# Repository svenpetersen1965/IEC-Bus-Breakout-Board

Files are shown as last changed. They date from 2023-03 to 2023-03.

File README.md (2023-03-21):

# IEC-Bus-Breakout-Board
This is a breakout board for the Commodore C64/C128/C16/VIC-20 etc. IEC-Bus. The Purpose is connecting the IEC-Bus to a µController or miniComputer, like an Arduino, a Raspberry Pi (zero, pico, Pi1-4) etc.

It provides the required interface ICs and even 5V to 3.3V level shifters, which are required for e.g. the raspberry pis.

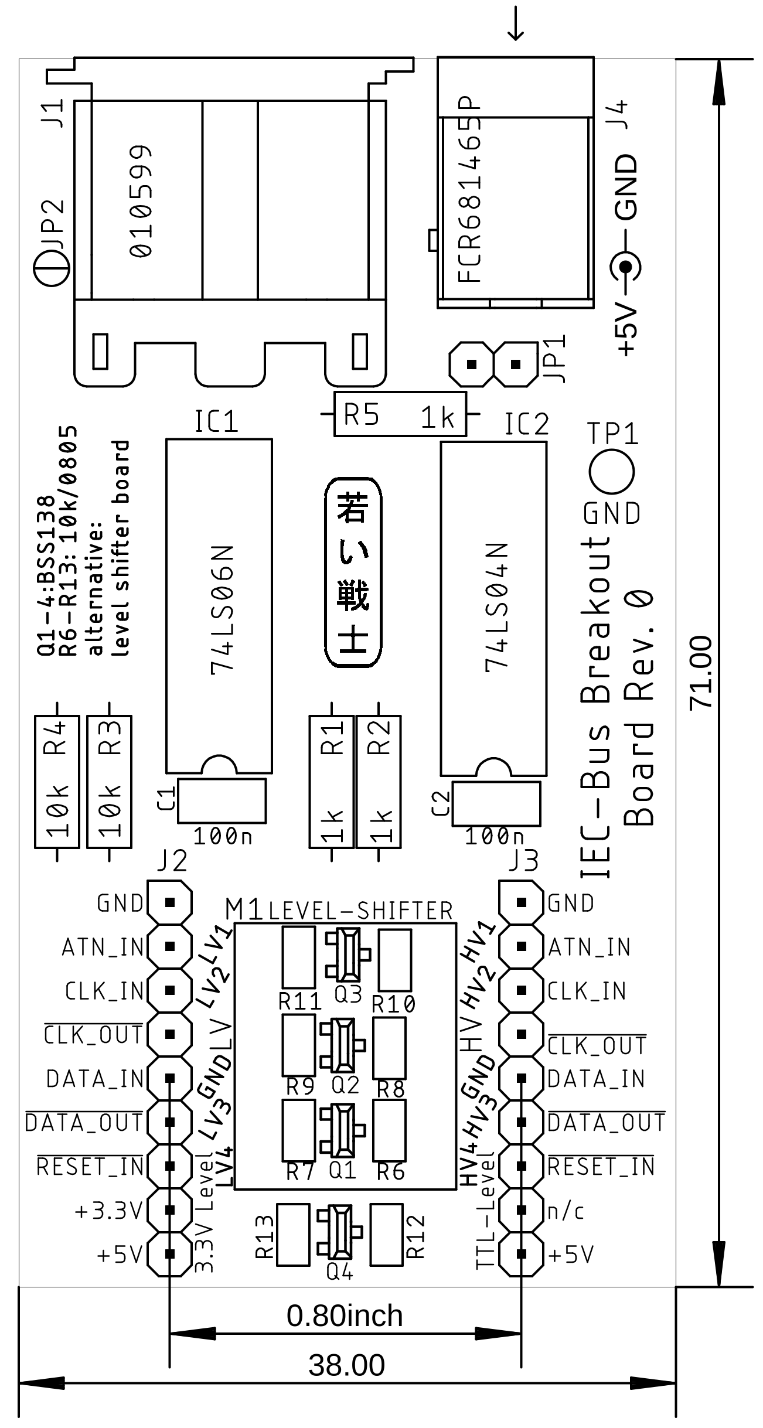
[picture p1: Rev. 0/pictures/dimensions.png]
IEC-Bus Breakout Board


<b>This design is not yet tested, and this is a preliminary release.</b>

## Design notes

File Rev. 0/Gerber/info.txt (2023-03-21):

      
       Board: IEC-Breakout
       Rev.:  0
  
       Files:
       ======
  
       All Gerber files are generated in extended gerber format (RS274X)
       *.TOP        : Film top copper
       *.BOT        :  -"- bottom copper
       *.STC        :  -"- top soldermask 
       *.STS        :  -"- bottom soldermask
       *.PLC        :  -"- silk screen top
       *.PLS        :  -"- silk screen bottom
       *.CRC        :  -"- cream top
       *.DK         : Drills plated Through (Excellon)
       *.NDK        : Drills not plated Through (Excellon)
       *.OUT        : Board outline

       Board Size:
       ===========
       Length     :   71.0 mm
       Width      :   38.0 mm
       Thickness  :   1.6 mm
       Material   :   FR 4
       Copper     :   35 um
       Surface    :   HASL
       
       Remarks:
       ========
       width > 6mil
       distane >= 6 mil
       drill >= 6mil

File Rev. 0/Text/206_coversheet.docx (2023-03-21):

Project Documentation

IEC-Bus Breakout Board

Project number: 206

Revision: 0

Date: 31.03.2023

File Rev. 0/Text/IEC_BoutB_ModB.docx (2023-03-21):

IEC-Bus Breakout Board Rev. 0

Module Description

This board serves as a breakout board for the Commodore IEC-bus. It already contains the required driver IC (74LS06) and a 74LS04 as a receiver (which resembles the original Commodore hardware).

The purpose is connecting the IEC-bus to microcontroller (modules) like an Arduino, as Raspberry Pi or a Raspberry Pi pico microcontroller. It would be possible to wire up a Pi1541 drive emulator.

For the Raspberry Pis, a lever shifter5 circuit is required, which is also implemented in this board. It can either be placed on-board as SMD components (8x 10k 0805 resistors and 4x BSS138 SOT-23 transistors). Alternatively, a pretty common level shifter module can be soldered to the board or put on soldered in socket strips.

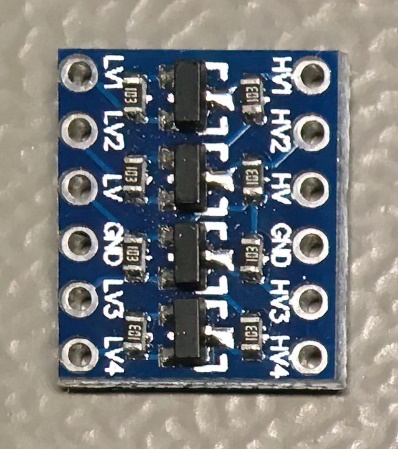
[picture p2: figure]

Figure 1: Level shifter module board

The dimensions of the level shifter module are approximately 12.7mm x 15.3mm. It is almost a standard module, which is available from AliExpress, Ebay, Amazon etc.

# Pinouts

## J1 - IEC-Bus

Lumberg 010599 06, 6p DIN receptacles

Pin | Signal
1 | /SRQ (not used in this design)
2 | GND
3 | ATN
4 | CLK
5 | DATA
6 | /RESET

## J4 - +5VDC Power

5,5mm/2,5mm barrel connector

Pin | Signal
Inner lead | +5VDC
Outer lead | GND

## J2 - 3.3V Level Pin Header

1x9 pin header (2.54mm)

Pin | Signal | Direction
1 | GND | -
2 | ATN_IN | µC input
3 | CLK_IN | µC input
4 | | µC output
5 | DATA_IN | µC input
6 | | µC output
7 | | µC input
8 | +3.3V | -
9 | +5V | -

## J3 – 5V (TTL) Level Pin Header

1x9 pin header (2.54mm)

Pin | Signal | Direction
1 | GND | -
2 | ATN_IN (5V) | µC input
3 | CLK_IN (5V) | µC input
4 | | µC output
5 | DATA_IN (5V) | µC input
6 | | µC output
7 | (5V) | µC input
8 | Not connected | -
9 | +5V | -

# Dimensions

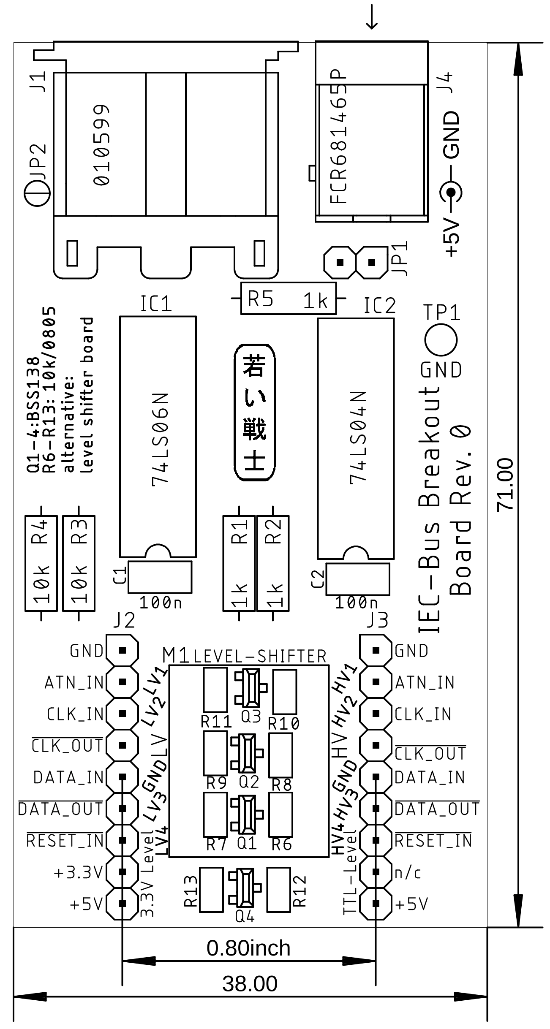
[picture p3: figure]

Figure 2: Dimensions of the IEC-bus breakout board

The distance of the pin headers J2 and J3 is 800mil. The pin headers can be place on the component side or the solder side of the board to fit it on a bread board. The width might be too wide to allow access to the receptacle rows. Standard DuPont wires can also serve to connect the board to the micro controller or a Raspberry Pi.

# Revision History

## Rev. 0

- Untested prototype

IEC_BoutB_ModB.docx 21.03.2023 21:46 Drafted by Sven Petersen Page 2 of 2 Doc.-No.: 206-6-01-00

IEC_BoutB_ModB.docx 21.03.2023 21:46 Drafted by Sven Petersen Page 1 of 1 Doc.-No.: 000-6-00-00

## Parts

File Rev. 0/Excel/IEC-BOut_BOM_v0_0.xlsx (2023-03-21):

IEC-Bus Breakout Board Rev. 0
Bill of Material Rev. 0.0
Pos. | Qty | Value | Footprint | Ref.-No. | Comment
1 | 1 | 206-2-01-00 | 2 Layer | PCB Rev. 0 | 2 layer, Cu 35µ, HASL, 71.0mm x 38.0mm, 1.6mm FR4
 | 2 | 1x9 pin header, 2.54mm | 1X09 | J2, J3 | standard pin header
 | 1 | 010599 | 10599 | J1 | Lumberg, e.g. Reichelt 010599 06, tme.eu: 0105-06
 | 2 | 100n | C-2,5 | C1, C2 | 100n/50V ceramic capacitor, 2.54mm pitch
 | 8 | 10k | 0805 | R6, R7, R8, R9, R10, R11, R12, R13 | SMD 0805, 5% or better, for on-board level shifter
 | 2 | 10k | R-10 | R3, R4 | THT resistor, 0.5W, 5%
 | 3 | 1k | R-10 | R1, R2, R5 | THT resistor, 0.5W, 5%
 | 1 | 74LS04N | DIL-14 | IC2 | Logic IC (TTL)
 | 1 | 74LS06N | DIL-14 | IC1 | Logic IC (TTL)
 | 4 | BSS138 | SOT23 | Q1, Q2, Q3, Q4 | MOSFET, for on-board level shifter
 | 1 | COMBI_2P | COMBI-2P | JP1 | for power switch, or solderbridge for always on
 | 1 | FCR681465P | FCR681465P | J4 | Cliff, Reichelt: CLIFF FCR681465P, tme.eu: FCR681465P
 | 1 | L1,2_R | 1,2MM_R | TP1 | dnp, GND pin for debugging purposes
 | 1 | LEVEL-SHIFTER | L-SHIFTER | M1 | Level shifter module, in case, the onboard level shifter circuit is not placed

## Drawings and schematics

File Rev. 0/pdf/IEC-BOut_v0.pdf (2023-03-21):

# Project Documentation

## IEC-Bus Breakout Board

## Project number: 206

## Revision: 0

## Date: 31.03.2023

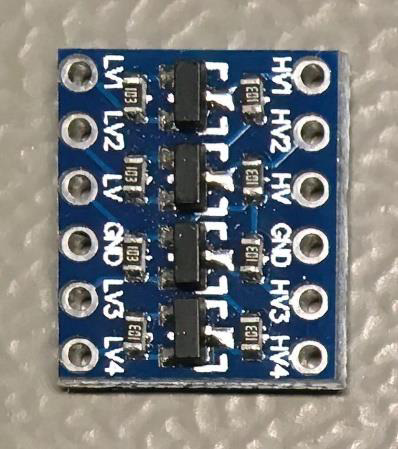
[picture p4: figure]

IEC_BoutB_ModB.docx | | 21.03.2023 21:46
Drafted by Sven Petersen | Page 1 of 3 | Doc.-No.: 206-6-01-00

### IEC-Bus Breakout Board Rev. 0

### Module Description

This board serves as a breakout board for the Commodore IEC-bus. It already contains the required driver IC (74LS06) and a 74LS04 as a receiver (which resembles the original Commodore hardware).

The purpose is connecting the IEC-bus to microcontroller (modules) like an Arduino, as Raspberry Pi or a Raspberry Pi pico microcontroller. It would be possible to wire up a Pi1541 drive emulator.

For the Raspberry Pis, a lever shifter5 circuit is required, which is also implemented in this board. It can either be placed on-board as SMD components (8x 10k 0805 resistors and 4x BSS138 SOT-23 transistors). Alternatively, a pretty common level shifter module can be soldered to the board or put on soldered in socket strips.

Figure 1: Level shifter module board

The dimensions of the level shifter module are approximately 12.7mm x 15.3mm. It is almost a standard module, which is available from AliExpress, Ebay, Amazon etc.

## Pinouts

### J1 - IEC-Bus

Lumberg 010599 06, 6p DIN receptacles

Pin Signal
1 /SRQ (not used in this design) 2 GND
3 ATN
4 CLK
5 DATA
6 /RESET

### J4 - +5VDC Power

5,5mm/2,5mm barrel connector

Pin | Signal
Inner lead | +5VDC
Outer lead | GND

IEC_BoutB_ModB.docx | | 21.03.2023 21:46
Drafted by Sven Petersen | Page 2 of 3 | Doc.-No.: 206-6-01-00

### J2 - 3.3V Level Pin Header

1x9 pin header (2.54mm)

Pin | Signal | Direction
1 | GND | -
2 | ATN_IN | µC input
3 | CLK_IN | µC input
4 | CLK_OUT | µC output
5 | DATA_IN | µC input
6 | DATA_OUT | µC output
7 | RESET_IN | µC input
8 | +3.3V | -
9 | +5V | -

### J3 – 5V (TTL) Level Pin Header

1x9 pin header (2.54mm)

Pin | Signal | Direction
1 | GND | -
2 | ATN_IN (5V) | µC input
3 | CLK_IN (5V) | µC input
4 | CLK_OUT | µC output
5 | DATA_IN (5V) | µC input
6 | DATA_OUT | µC output
7 | RESET_IN (5V) | µC input
8 | Not connected | -
9 | +5V | -


IEC_BoutB_ModB.docx | | 21.03.2023 21:46
Drafted by Sven Petersen | Page 3 of 3 | Doc.-No.: 206-6-01-00

## Dimensions

Figure 2: Dimensions of the IEC-bus breakout board

The distance of the pin headers J2 and J3 is 800mil. The pin headers can be place on the component side or the solder side of the board to fit it on a bread board. The width might be too wide to allow access to the receptacle rows. Standard DuPont wires can also serve to connect the board to the micro controller or a Raspberry Pi.

## Revision History

### Rev. 0

- Untested prototype

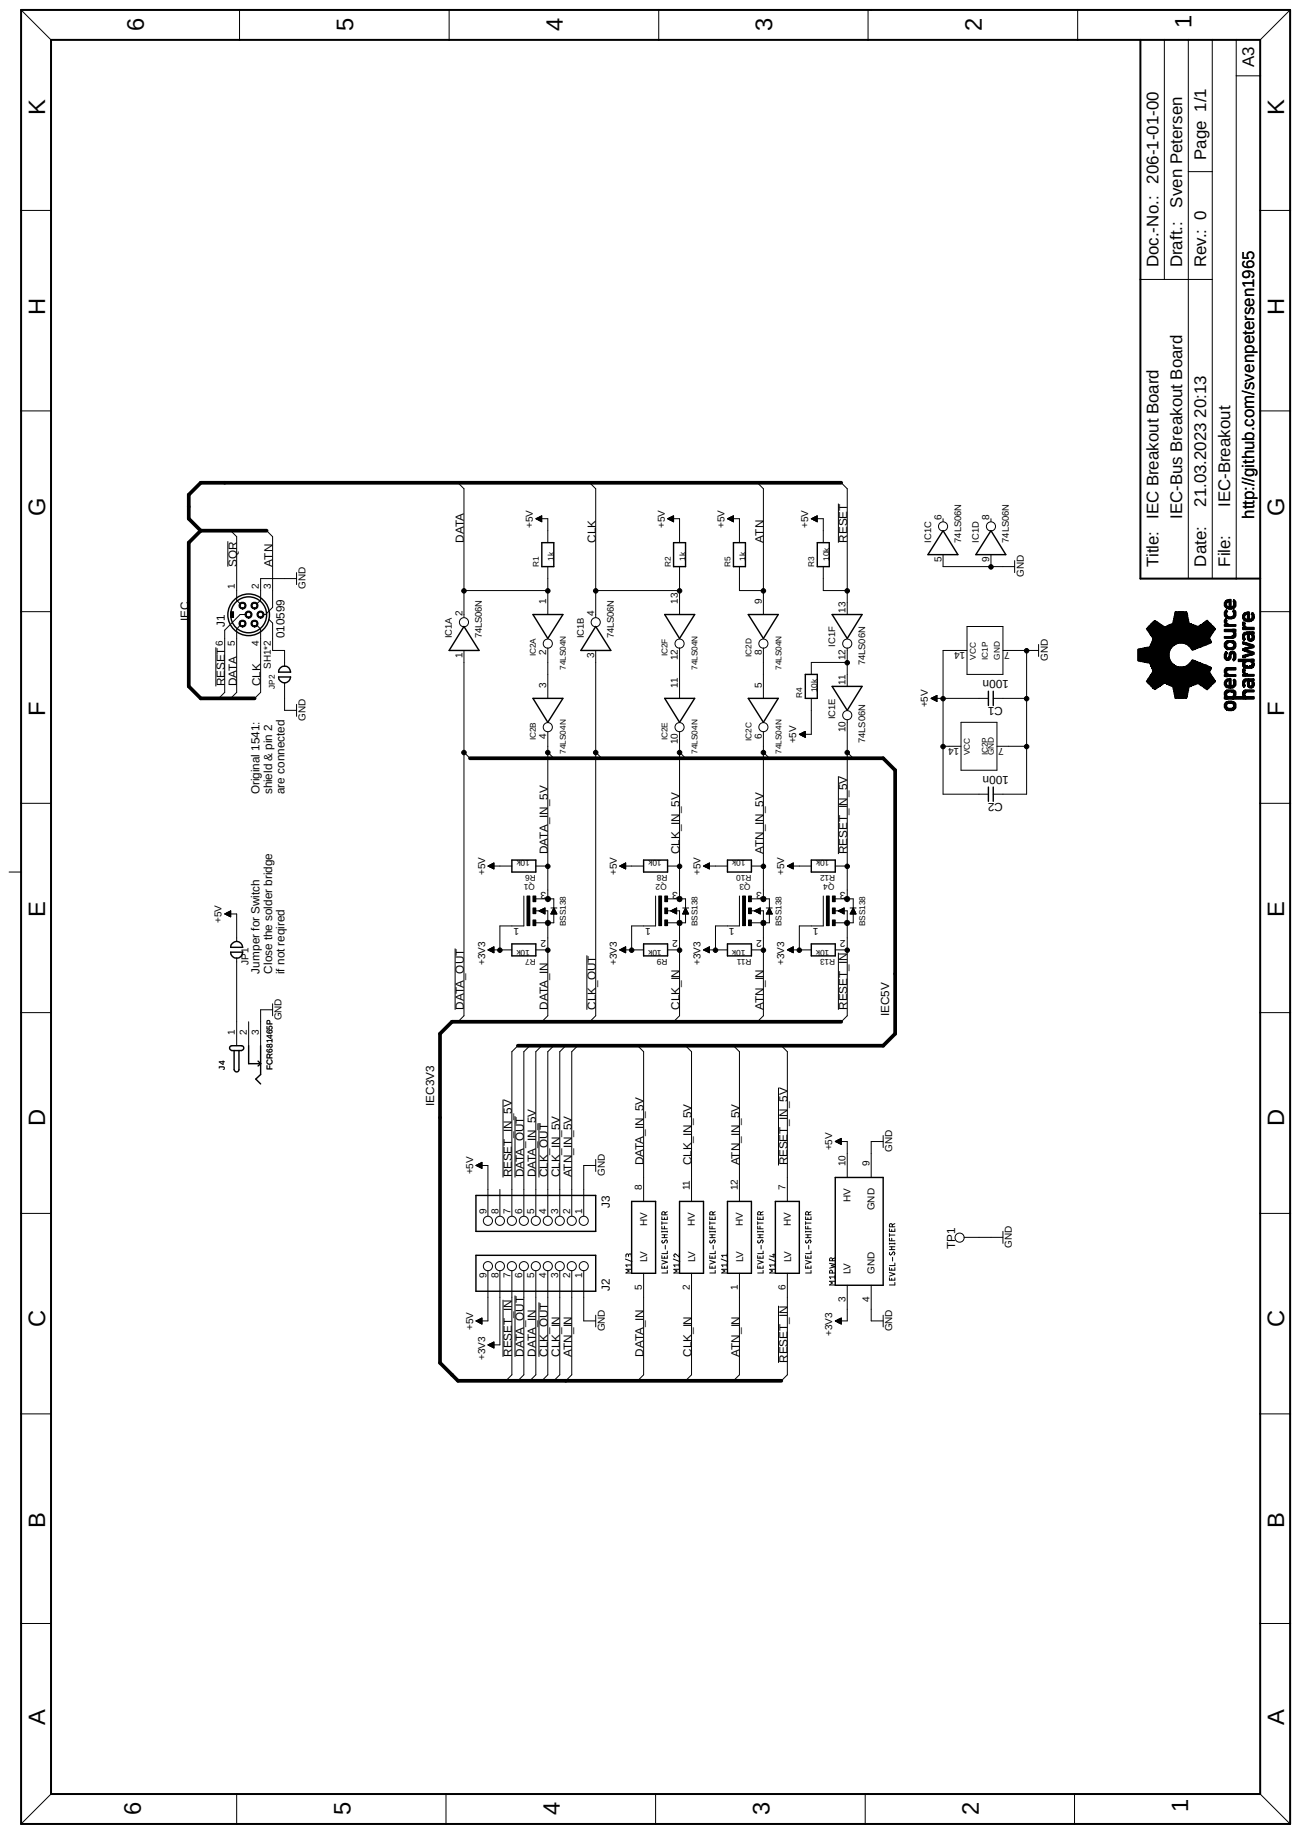
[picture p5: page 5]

IEC-Bus Breakout Board Sven Petersen

http://github.com/svenpetersen1965http://github.com/svenpetersen1965

Close the solder bridge

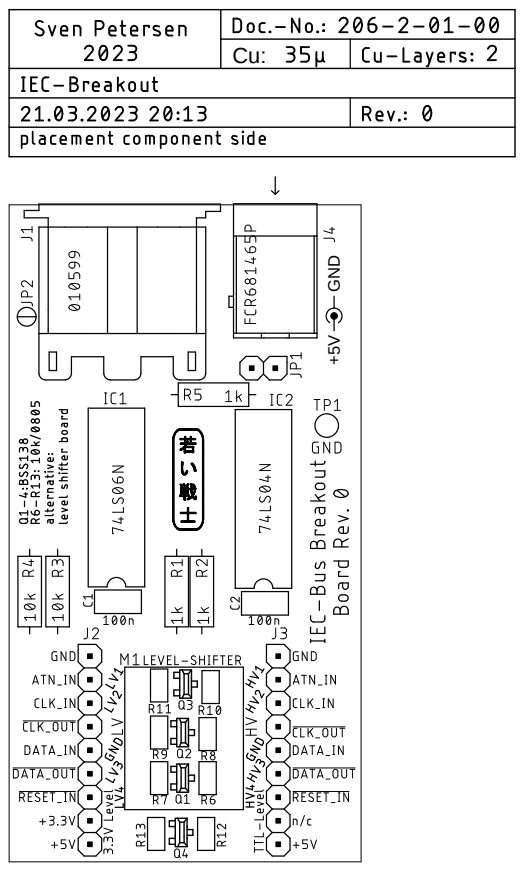
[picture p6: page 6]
+5V GND

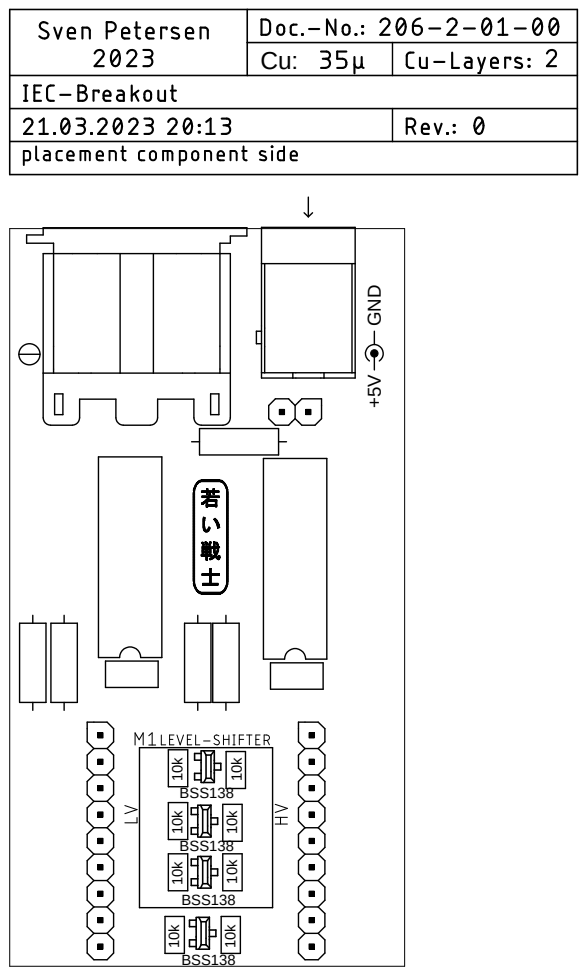
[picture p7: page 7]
+5V GND; BSS138; BSS138 ¹⁰k 10k

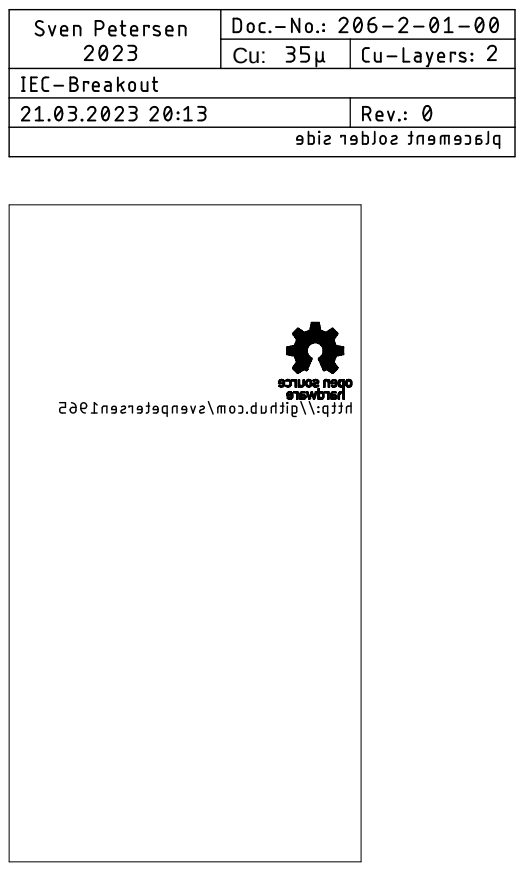
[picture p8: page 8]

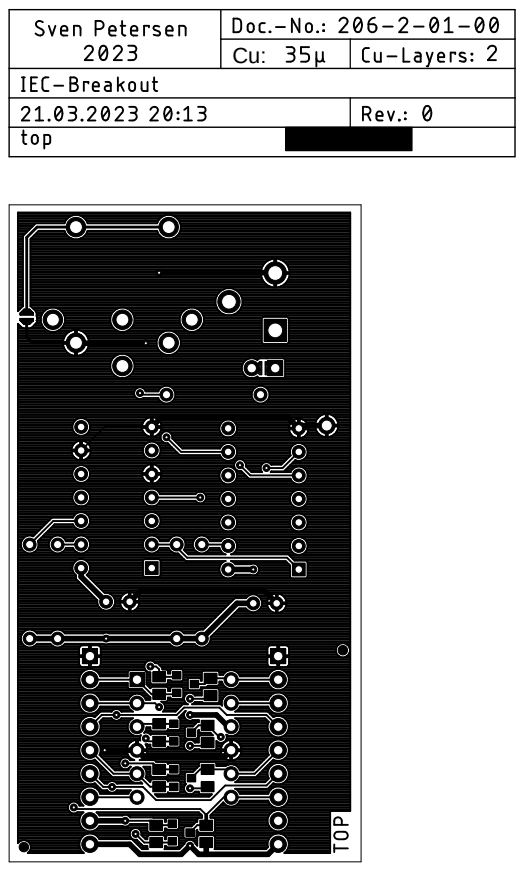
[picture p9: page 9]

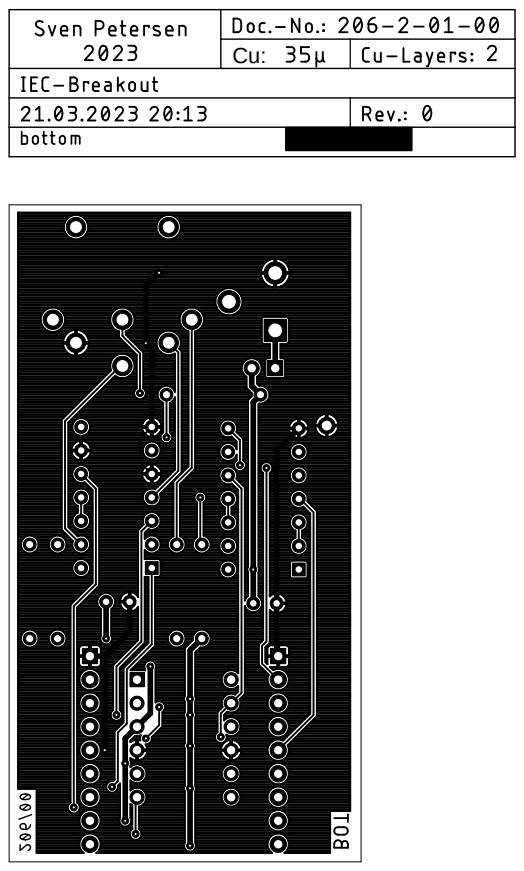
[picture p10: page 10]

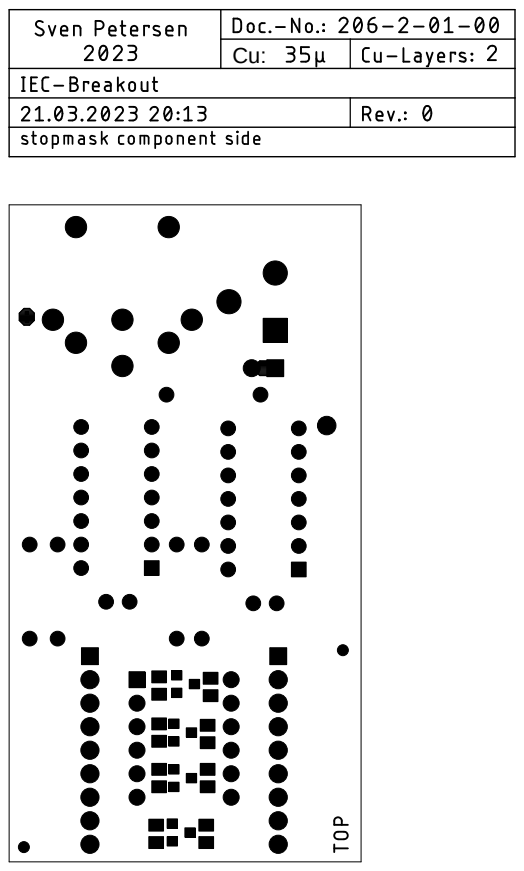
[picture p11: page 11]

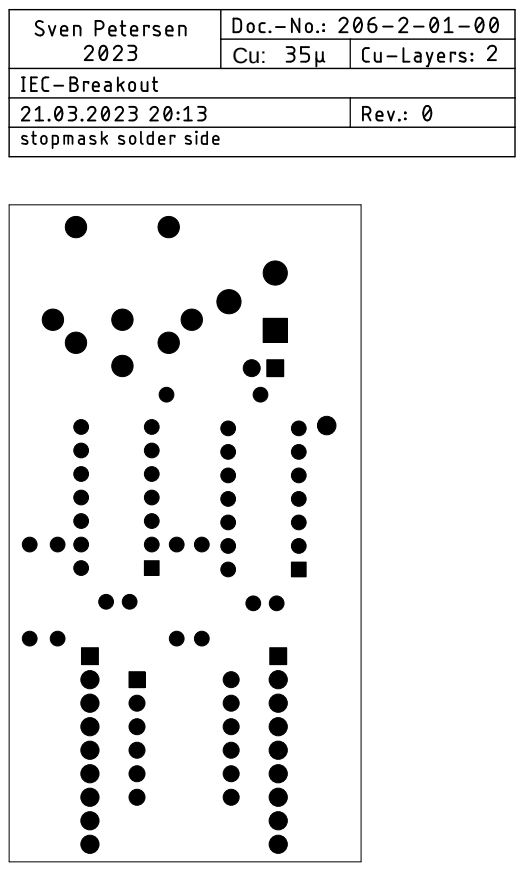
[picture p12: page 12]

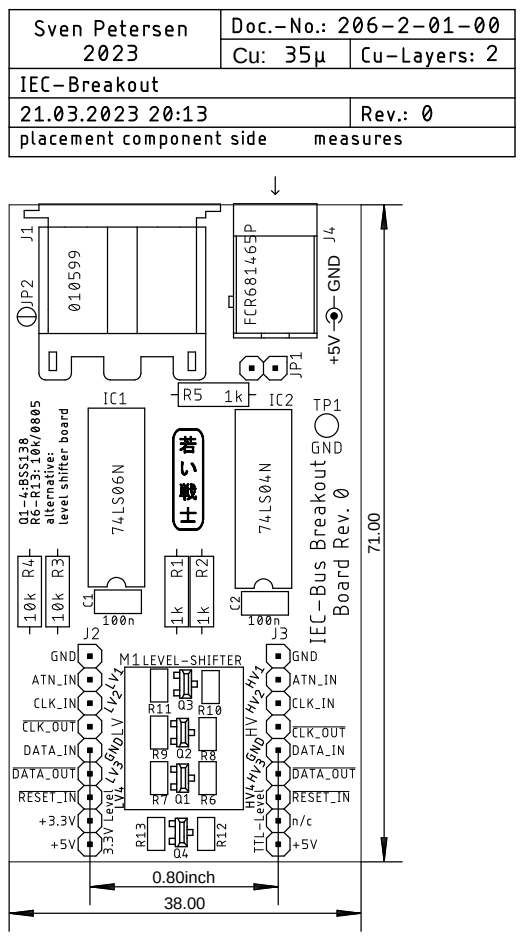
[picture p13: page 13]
+5V GND; 0.80inch

Pos. Qty Value Footprint Ref.-No. Comment

1 1 206-2-01-00 2 Layer PCB Rev. 0 2 layer, Cu 35µ, HASL, 71.0mm x 38.0mm, 1.6mm FR4

2 1x9 pin header, 2.54mm 1X09 J2, J3 standard pin header

1 010599 10599 J1 Lumberg, e.g. Reichelt 010599 06, tme.eu: 0105-06

2 100n C-2,5 C1, C2 100n/50V ceramic capacitor, 2.54mm pitch

8 10k 0805 R6, R7, R8, R9, R10, R11, R12,

R13

SMD 0805, 5% or better, for on-board level shifter

2 10k R-10 R3, R4 THT resistor, 0.5W, 5%
3 1k R-10 R1, R2, R5 THT resistor, 0.5W, 5%

1 74LS04N DIL-14 IC2 Logic IC (TTL)

1 74LS06N DIL-14 IC1 Logic IC (TTL)

### 4 BSS138 SOT23 Q1, Q2, Q3, Q4 MOSFET, for on-board level shifter

### 1 COMBI_2P COMBI-2P JP1 for power switch, or solderbridge for always on

### 1 FCR681465P FCR681465P J4 Cliff, Reichelt: CLIFF FCR681465P, tme.eu: FCR681465P

### 1 L1,2_R 1,2MM_R TP1 dnp, GND pin for debugging purposes

1 LEVEL-SHIFTER L-SHIFTER M1 Level shifter module, in case, the onboard level shifter circuit

is not placed

## IEC-Bus Breakout Board Rev. 0

## Bill of Material Rev. 0.0

IEC-BOut_BOM_v0_0.xlsx

Drafted by Sven Petersen Page 1 of 1

21.03.2023 20:46
Doc.No.: 206-5-01-00.0

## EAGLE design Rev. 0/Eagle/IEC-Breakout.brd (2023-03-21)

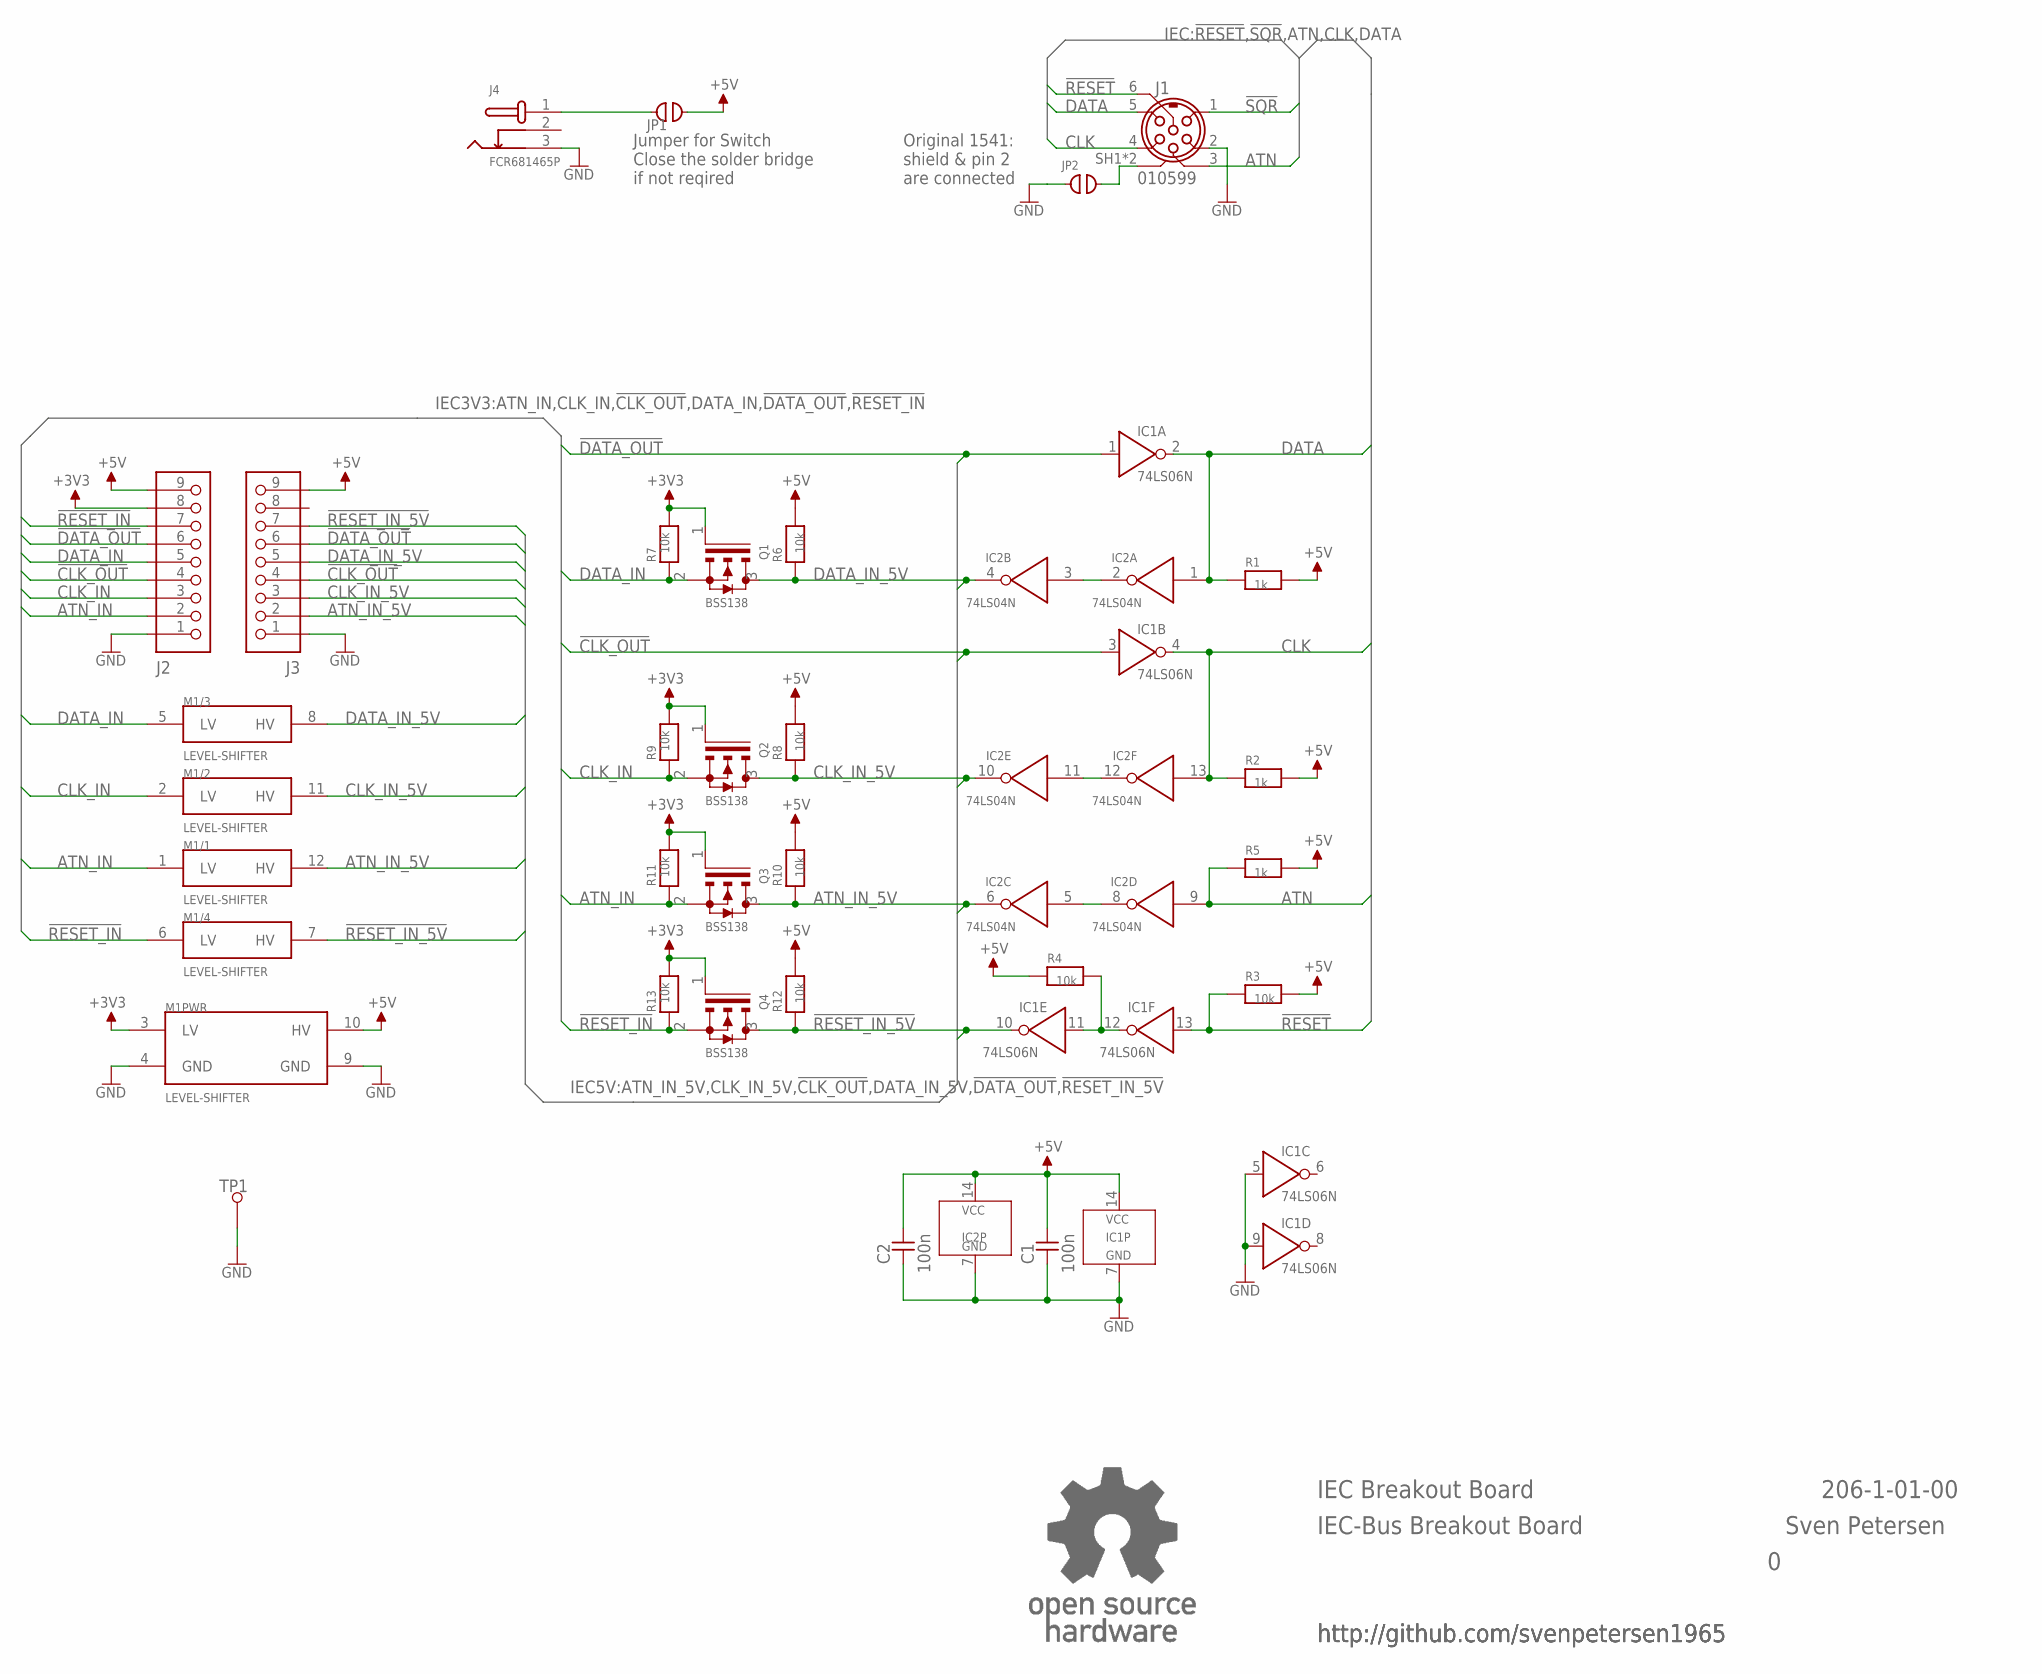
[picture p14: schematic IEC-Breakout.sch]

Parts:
C1, C2: 100n; C-2,5
IC1: 74LS06N; DIL-14
IC2: 74LS04N; DIL-14
J1: 010599
J2, J3: PINHD-1X9; 1X09
J4: FCR681465P
JP1: COMBI_2P; COMBI-2P
JP2: OPEN; CP_OP
M1: LEVEL-SHIFTER; L-SHIFTER
Q1, Q2, Q3, Q4: BSS138; SOT23
R1, R2, R5: 1k; R-10
R3, R4: 10k; R-10
R6, R7, R8, R9, R10, R11, R12, R13: 10k; 0805
TP1: L1,2_R; 1,2MM_R
U$31: OPEN_SOURCE_HW; OPENHW

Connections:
!CLK_OUT: IC1.3 (I), J2.4, J3.4
!DATA_OUT: IC1.1 (I), J2.6, J3.6
!RESET: IC1.13 (I), J1.6, R3.1
!RESET_IN: J2.7, M1.6 (LV), Q4.2 (S), R13.1
!RESET_IN_5V: IC1.10 (O), J3.7, M1.7 (HV), Q4.3 (D), R12.1
!SQR: J1.1
+3V3: J2.8, M1.3 (LV), Q1.1 (G), Q2.1 (G), Q3.1 (G), Q4.1 (G), R7.2, R9.2, R11.2, R13.2
+5V: C1.2, C2.2, IC1.14 (VCC), IC2.14 (VCC), J2.9, J3.9, JP1.2, M1.10 (HV), R1.2, R2.2, R3.2, R4.1, R5.2, R6.2, R8.2, R10.2, R12.2
ATN: IC2.9 (I), J1.3, R5.1
ATN_IN: J2.2, M1.1 (LV), Q3.2 (S), R11.1
ATN_IN_5V: IC2.6 (O), J3.2, M1.12 (HV), Q3.3 (D), R10.1
CLK: IC1.4 (O), IC2.13 (I), J1.4, R2.1
CLK_IN: J2.3, M1.2 (LV), Q2.2 (S), R9.1
CLK_IN_5V: IC2.10 (O), J3.3, M1.11 (HV), Q2.3 (D), R8.1
DATA: IC1.2 (O), IC2.1 (I), J1.5, R1.1
DATA_IN: J2.5, M1.5 (LV), Q1.2 (S), R7.1
DATA_IN_5V: IC2.4 (O), J3.5, M1.8 (HV), Q1.3 (D), R6.1
GND: C1.1, C2.1, IC1.5 (I), IC1.7 (GND), IC1.9 (I), IC2.7 (GND), J1.2, J2.1, J3.1, J4.3, JP2.1, M1.4 (GND), M1.9 (GND), TP1.1
unnamed: J1.SH1 (SH), J1.SH2 (SH), JP2.2
unnamed: IC2.2 (O), IC2.3 (I)
unnamed: J4.1, JP1.1
unnamed: IC2.11 (I), IC2.12 (O)
unnamed: IC2.5 (I), IC2.8 (O)
unnamed: IC1.11 (I), IC1.12 (O), R4.2

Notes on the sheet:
Original 1541: shield & pin 2 are connected
Jumper for Switch Close the solder bridge if not reqired
IEC Breakout Board
IEC-Bus Breakout Board
Sven Petersen
206-1-01-00
http://github.com/svenpetersen1965

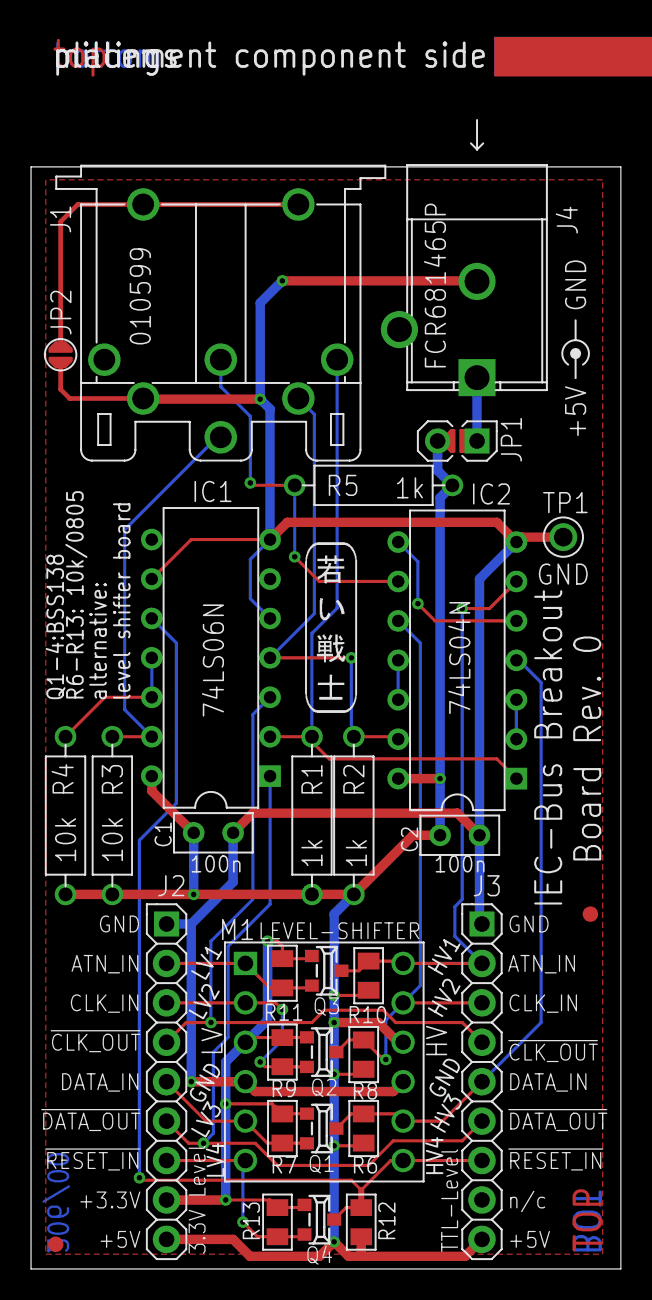
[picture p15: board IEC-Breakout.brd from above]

Board: 2 copper layers, 38.0 x 71.0 mm, 35 parts (1 on the bottom side), 23 nets.

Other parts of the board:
U$32: 2LAYER
U$33, U$34: SMD_REF_R1MM
U$35: PCB-TITLE/
U$36: SVEN_TAG
